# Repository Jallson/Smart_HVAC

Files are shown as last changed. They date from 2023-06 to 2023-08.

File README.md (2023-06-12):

# Smart_HVAC_by_Jallson_Suryo
### Problem:
The problem often found in HVAC systems is that energy got wasted because the system uses more energy than necessary or the system cannot quickly adjust to the changing needs in a dynamic environment. To tackle the problem, we need a system that manages its power intensity based on what is necessary for each zones in real-time for a given environment. The power intensity necessary for each zones can be derived from the following data: number of person, time duration spent inside, and/or the person’s activity.

### Our Solution:
Smart HVAC System that can optimize energy consumption by adjusting the power intensity in different zones inside an office or a residential space (zones with more people, more activity and longer time durations will need more cooling/heating and vice versa). The zone heat mapping will be generated using data obtained from Nicla Vision (with Edge Impulse's FOMO ML model embedded) that’s mounted like a surveillance camera inside the space.

### Description:
The project uses Edge Impulse’s FOMO to detect multiple objects and its coordinates using a compact micro-controller with on-board camera (Nicla Vision). The object detection ML model will use the top view of miniature figures with standing and sitting positions as objects. The data captured will be divided into training and test data. Then the Impulse with Image and Object Detection as learning blocks and grayscale color blocks will be created. The accuracy result for this training and test model is above 90% so there is confidence when counting the number of objects (person) and tracking its centroid coordinates. The ML model is then deployed to the Nicla Vision. The number of objects in each zone is displayed into the OLED display. The Nicla Vision also communicates to an Arduino Nano via I2C which we are using for the fan speed controller. This system will increase fan intensity on areas/zone that need more cooling/heating, which means more activity/people on a certain zone will increase fan intensity on that zone. The total HVAC power output can also be adjusted based on the total number of people in the space. The project is a proof of concept (PoC) using a 1:50 scale model with an office interior with several partitions and furniture and miniature figures. The space is divided into 4 zones, each zone has a small fan installed. The OLED display is used in this PoC to show the output of this simulation.

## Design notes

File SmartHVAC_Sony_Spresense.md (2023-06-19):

## Smart HVAC System with Sony Spresense by Jallson Suryo

This is an alternative version of the Smart HVAC project using the Sony Spresense development board. The Nicla Vision version of this project can be found here: (https://github.com/Jallson/Smart_HVAC/blob/main/HVAC_Smart_System.md)

Demo Video link: https://youtu.be/LLYOtY7svDQ
Edge Impulse project link: https://studio.edgeimpulse.com/public/215243/latest


Smart HVAC with Sony Spresense camera - PoC Demo setup




Diagram Smart HVAC with Sony Spresense expansion board with Camera

All the steps from 1 to 5 (skipping part 4) is the same with the previous project; Sony Spresense does not use the Open MV IDE hence part 4 can be skipped. In part 5, Deploying the program via the Arduino IDE, we have modified the code, which can be downloaded here (https://github.com/Jallson/Smart_HVAC/blob/main/spresense_camera_smartHVAC_oled.ino) and the code for the Arduino Nano peripheral *Nano_SmartHVAC_I2C_Peripheral.ino* can be downloaded here (https://github.com/Jallson/Smart_HVAC/blob/main/Nano_SmartHVAC_I2C_Peripheral.ino).


### Conclusion
By using Sony Spresense, this Smart HVAC project successfully demonstrates that the flexibility of the ML model using Edge Impulse can be directly applied to different types of Micro-controllers with only minimal modification needed. This Sony Spresense development board has the potential with more RAM and a larger Sony camera sensor than the Nicla Vision.

Additional case design for Sony Spresense for this project:



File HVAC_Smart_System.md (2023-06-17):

## Smart HVAC System with Nicla Vision by Jallson Suryo



Edge Impulse project link: https://studio.edgeimpulse.com/public/215243/latest
Demo Video link (unlisted): https://youtu.be/QgQMWRZAlcY

### Problem:
The problem often found in HVAC systems is that energy got wasted because the system uses more energy than necessary or the system cannot quickly adjust to the changing needs in a dynamic environment. To tackle the problem, we need a system that manages its power intensity based on what is necessary for each zones in real-time for a given environment. The power intensity necessary for each zones can be derived from the following data: number of person, time duration spent inside, and/or the person’s activity.

### Our Solution:
Smart HVAC System that can optimize energy consumption by adjusting the power intensity in different zones inside an office or a residential space (zones with more people, more activity and longer time durations will need more cooling/heating and vice versa). The zone heat mapping will be generated using data obtained from Nicla Vision (with Edge Impulse's FOMO ML model embedded) that’s mounted like a surveillance camera inside the space.

### Description:
The project uses Edge Impulse’s FOMO to detect multiple objects and its coordinates using a compact micro-controller with on-board camera (Nicla Vision). The object detection ML model will use the top view of miniature figures with standing and sitting positions as objects. The data captured will be divided into training and test data. Then the Impulse with Image and Object Detection as learning blocks and grayscale color blocks will be created.
The accuracy result for this training and test model is above 90% so there is confidence when counting the number of objects (person) and tracking its centroid coordinates.

The ML model is then deployed to the Nicla Vision. The number of objects in each zone is displayed into the OLED display. The Nicla Vision also communicates to an Arduino Nano via I2C which we are using for the fan speed controller.
This system will increase fan intensity on areas/zone that need more cooling/heating, which means more activity/people on a certain zone will increase fan intensity on that zone. The total HVAC power output can also be adjusted based on the total number of people in the space. 
The project is a proof of concept (PoC) using a 1:50 scale model with an office interior with several partitions and furniture and miniature figures. The space is divided into 4 zones, each zone has a small fan installed. The OLED display is used in this PoC to show the output of this simulation.





Arduino Nicla Vision, aluminium extrusion frame, and 3D printed miniature model (1:50)
System Diagram , prototyping in breadboard, and Smart HVAC System with custom design PCB

#### Hardware Component:

- Arduino Nicla Vision
- Arduino Nano
- 2x TB6612 Motor drivers
- 4x DC 5V mini fan 3cm
- 0.96inch OLED display
- Aluminium extrusion as a standee
- 3D printed (case, office interior 1:50 miniature)
- Powerbank & battery for Nicla Vision

#### Software & Online Services:

- Edge Impulse Studio
- Arduino IDE
- OpenMV IDE

### Steps:

#### 1. Prepare Data / Photos

In this project we will use a smartphone camera to capture the images for data collection for ease of use. Take picture from above in different positions with backgrounds of varying angles lighting condition to ensure that the model can work under slightly different conditions (to prevent overfitting). FYI, lighting and object size are crucial aspect to ensure the performance of this model.
Note: Keep the size of the objects similar in size in the pictures. Significant difference in object size will confuse the FOMO algorithm.

#### 2. Data acquisition, and labelling

Open studio.edgeimpulse.com , login (or create an account first) then create a new project.
Choose Images project option, then Classify Multiple Objects. In Dashboard > Project Info, choose Bounding Boxes for labelling method and Nicla Vision for target device. Then in Data acquisition, click on Upload Data tab, choose your photo files, auto split, then click Begin upload.
Click on Labelling queue tab then start drag a box around an object and label it (person) and Save. Repeat.. until all images labelled. 



Make sure that the ratio between Training and Test data is ideal, around 80/20.

#### 3. Training and building model using FOMO Object Detection
Once you have the dataset ready, go to Create Impulse and set 96 x 96 as image width - height (this help in keeping the ML model small in memory size). Then choose Fit shortest axis, and choose Image and Object Detection as learning blocks.
Go to Image parameter section, select color depth as Grayscale then press Save parameters. Then click on Generate and navigate to Object Detection section, and leave training setting for Neural Network as it is — in our case is quite balanced pre-trained model, then we choose FOMO (MobileNet V2 0.35). Train the model by press the Start training.. and you can see the progress.
If everything is OK, then we can test the model, go to Model Testing section and click Classify all. Our result is above 90%, then we can move on to the next step — deployment.






#### 4. Deploy to OpenMV firmware and test it.



To use the OpenMV firmware, you will need the OpenMV IDE installed in your computer. Once you have the IDE ready, if you check the downloaded zip folder you will find a number of files. We will need the following files:
*edge_impulse_firmware_arduino_nicla_vision.bin* and *ei_object_detection.py*. The next step is loading the downloaded firmware containing the ML model to the Nicla Vision board. So go back to OpenMV and go to Tools -> Run Bootloader (Load Firmware), select the *.bin* file in the unzipped folder, and click Run.

Next, we will run the python code. Go to File -> Open File and select the .py python file from the unzipped folder. Once the file is opened, connect the Nicla Vision board, select the serial/com port and click the green “play” button. The program should be running now and you can see the FOMO object detection will run live on a small window.


#### 5. Deploy and Build an Arduino program



You should have the Arduino IDE installed on your computer for the following step. Once the Edge Impulse Arduino Firmware is built, downloaded and unzipped, you should download the *nicla_vision_camera_smartHVAC_oled.ino* code which can be downloaded here (https://github.com/Jallson/Smart_HVAC/blob/main/nicla_vision_camera_smartHVAC_oled.ino) and place it inside the unzipped folder from Edge Impulse. Once the *.ino* code is inside Edge Impulse unzipped folder, move it to your Arduino folder on your computer. Now you can upload the *.ino* code to your Nicla Vision board via the Arduino IDE.
The *.ino code* is a modified version of the Edge Impulse example code for object detection on Nicla Vision. The modification adds capability to display person count on each room to the OLED screen and act as the controller to the Arduino Nano I2C peripheral. The code distinguishes the four rooms using four quadrants and by knowing the X, Y coordinates of the object’s centroid we can locate the person. The Arduino Nano adjusts the fan motor using PWM based on the number of person present in the room.

The code for the Arduino Nano peripheral *Nano_SmartHVAC_I2C_Peripheral.ino* can be downloaded here (https://github.com/Jallson/Smart_HVAC/blob/main/Nano_SmartHVAC_I2C_Peripheral.ino).

Prototype test video: https://youtube.com/shorts/DnW0lFKFCdk?feature=share

### Conclusion

Finally, we have successfully implemented this object detection model into Arduino Nicla Vision and use the data captured from the camera to automatically control the HVAC system’s fans’ power intensity and then display the occupancy number and power meter for each zones. I believe this Proof of Concept project can be implemented in the real world HVAC system, so that the goal of optimizing room temperature and saving energy can be achieved for a better more sustainable future.

Check again our complete demo video: 
https://youtu.be/QgQMWRZAlcY

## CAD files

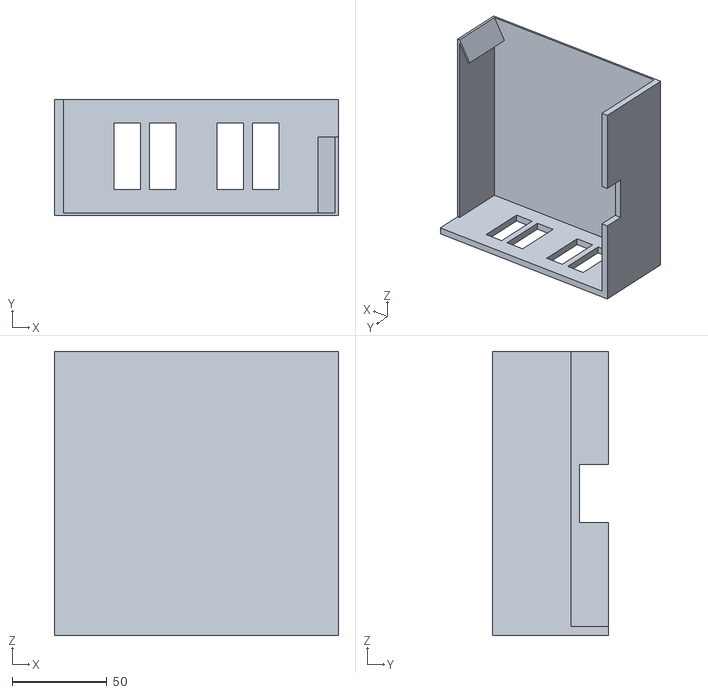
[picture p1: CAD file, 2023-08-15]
3d_files/plan_office 1of4.stl
150.0 x 61.4 x 150.0

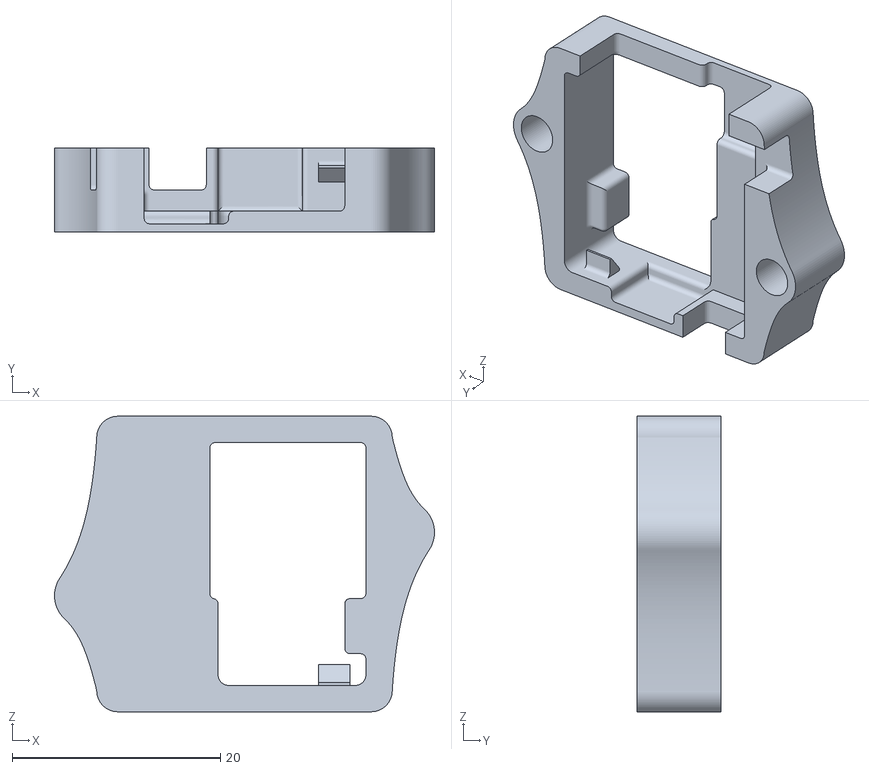
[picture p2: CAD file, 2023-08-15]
3d_files/Nicla_front.stl
36.5 x 8.12 x 28.4

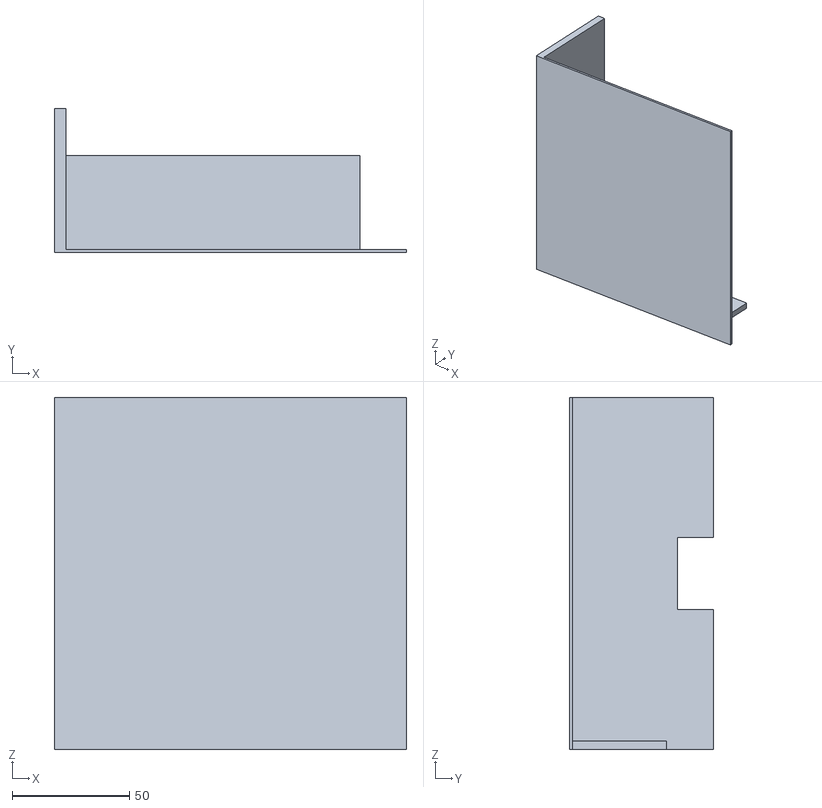
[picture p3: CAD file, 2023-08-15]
3d_files/plan_office 2of4.stl
150.0 x 61.4 x 150.0

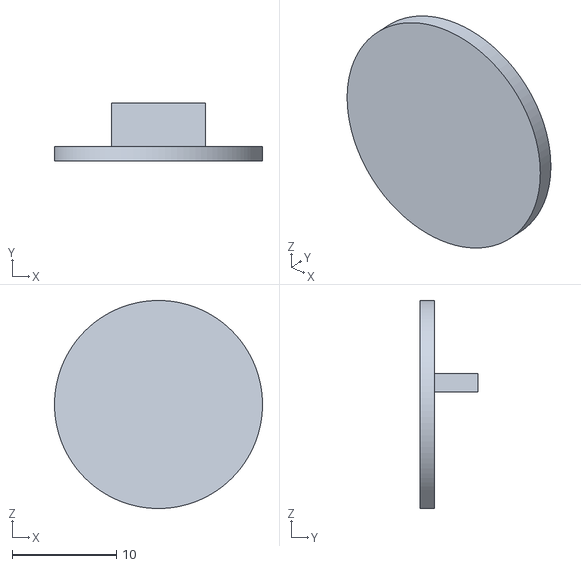
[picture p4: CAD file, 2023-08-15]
3d_files/figure_standing_pad.stl
20.0 x 5.60 x 20.0

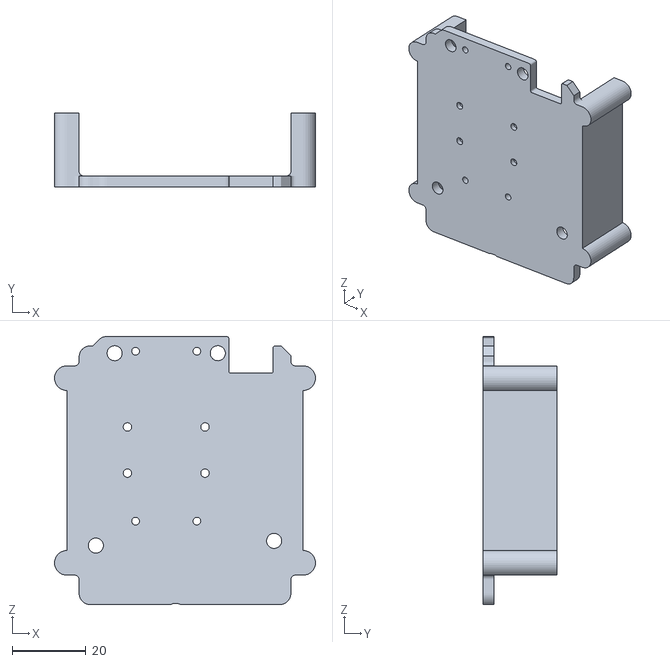
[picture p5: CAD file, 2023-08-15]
3d_files/sony_bottomcase_hvac.stl
70.7 x 20.0 x 72.6

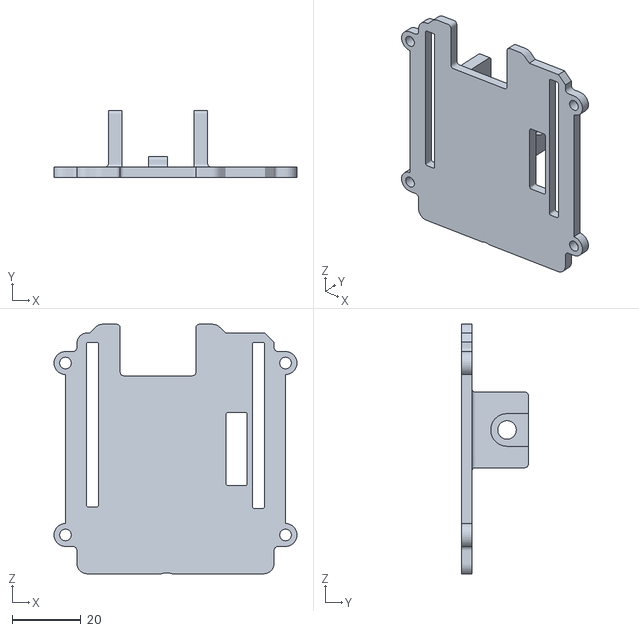
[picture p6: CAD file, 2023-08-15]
3d_files/Sony_topcase_hvac.stl
70.7 x 19.4 x 72.6

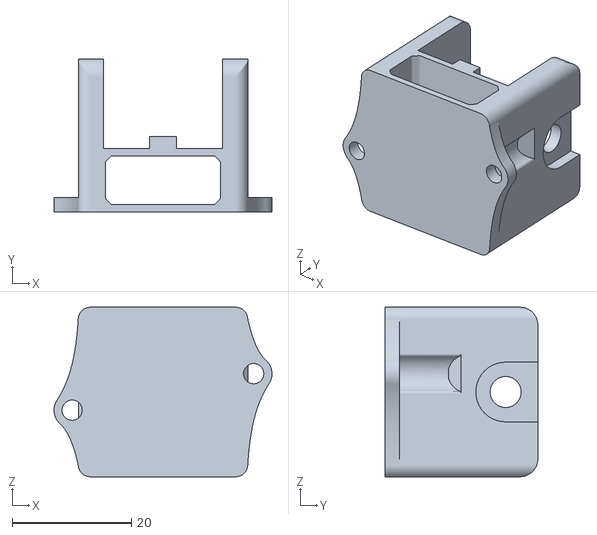
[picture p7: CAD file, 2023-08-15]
3d_files/Nicla_Bottom.stl
36.5 x 25.6 x 28.4

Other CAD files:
3d_files/plan_office 3of4.stl
3d_files/plan_office 4of4.stl

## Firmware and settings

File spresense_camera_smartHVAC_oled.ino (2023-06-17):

 /***
 * Some of this code came from edge impulse's example and                           *
 * modifications to M. Marcial's code.                                              *
 * Hence, the following Edge Impulse and M. Marcial's copyright statement.          *
 *----------------------------------------------------------------------------------*
 * Edge Impulse Arduino examples                                                    *
 * Copyright (c) 2021 EdgeImpulse Inc.                                              *
 * M. Marcial "Spresense-VisionModel.ino"                                           *
 * Copyright (c) 2022 M. Marcial                                                    *
 *                                                                                  *
 * Permission is hereby granted, free of charge, to any person obtaining a copy     *
 * of this software and associated documentation files (the "Software"), to deal    *
 * in the Software without restriction, including without limitation the rights     *
 * to use, copy, modify, merge, publish, distribute, sublicense, and/or sell        *
 * copies of the Software, and to permit persons to whom the Software is            *
 * furnished to do so, subject to the following conditions:                         *
 *                                                                                  *
 * The above copyright notice and this permission notice shall be included in       *
 * all copies or substantial portions of the Software.                              *
 *                                                                                  *
 * THE SOFTWARE IS PROVIDED "AS IS", WITHOUT WARRANTY OF ANY KIND, EXPRESS OR       *
 * IMPLIED, INCLUDING BUT NOT LIMITED TO THE WARRANTIES OF MERCHANTABILITY,         *
 * FITNESS FOR A PARTICULAR PURPOSE AND NONINFRINGEMENT. IN NO EVENT SHALL THE      *
 * AUTHORS OR COPYRIGHT HOLDERS BE LIABLE FOR ANY CLAIM, DAMAGES OR OTHER           *
 * LIABILITY, WHETHER IN AN ACTION OF CONTRACT, TORT OR OTHERWISE, ARISING FROM,    * 
 * OUT OF OR IN CONNECTION WITH THE SOFTWARE OR THE USE OR OTHER DEALINGS IN THE    *
 * SOFTWARE.                                                                        *
 *                                                                                  *
 ************************************************************************************
 ***/

////////////////////////////////////////////////////////////////////////////////////////////////////////////////////
//                      MEMORY INFO                                                                               //
//                      The program requires a minimum MainCore memory of 1024 kB                                 //
////////////////////////////////////////////////////////////////////////////////////////////////////////////////////

/***
//------------------------------------------------------------------------------------------------------------------
  Edge Impulse Studio float32 Library Estimates: RAM 131k, Flash 182
//------------------------------------------------------------------------------------------------------------------

  Target 1152 kB
  *** ---> Works!
  Sketch uses           393,424 bytes (33%) of program storage space.
  Maximum is          1,179,648 bytes.
  Global variables use  393,424 bytes (33%) of dynamic memory,
  leaving               786,224 bytes for local variables.
  Maximum is          1,179,648 bytes.

  Target 1024 kB
  *** ---> Works!
  Sketch uses           393,392 bytes (37%) of program storage space.
  Maximum is          1,048,576 bytes.
  Global variables use  393,392 bytes (37%) of dynamic memory,
  leaving               655,184 bytes for local variables.
  Maximum is          1,048,576 bytes.
  
  Target 896 kB
  *** --->  ERR: failed to allocate tensor arena
                 Failed to allocate TFLite arena (error code 1)
                 ERROR: Failed to run classifier in camera_classify(). Err=-6
  Sketch uses           393,336 bytes (42%) of program storage space.
  Maximum is            917,504 bytes.
  Global variables use  393,336 bytes (42%) of dynamic memory,
  leaving               524,168 bytes for local variables.
  Maximum is            917,504 bytes.                 

  Target 768 kB
  *** ---> Executes CamCB() once then crashes
  Sketch uses           393,336 bytes (50%) of program storage space.
  Maximum is            786,432 bytes.
  Global variables use  393,336 bytes (50%) of dynamic memory,
  leaving               393,096 bytes for local variables.
  Maximum is            786,432 bytes.
  
  Target 640 kB
  *** ---> Executes CamCB() once then crashes
  Sketch uses            393,336 bytes (60%) of program storage space.
  Maximum is             655,360 bytes.
  Global variables use   393,336 bytes (60%) of dynamic memory,
  leaving                262,024 bytes for local variables.
  Maximum is             655,360 bytes.
  
  Target 512 kB
  *** ---> Gets to loop(), then crashes.
  Sketch uses           393,336 bytes (74%) of program storage space.
  Maximum is            524,288 bytes.
  Global variables use  393,336 bytes (74%) of dynamic memory,
  leaving               130,952 bytes for local variables.
  Maximum is            524,288 bytes.

////////////////////////////////////////////////////////////////////////////////////////////////////////////////////
//                      PROGRAMMING INFO                                                                          //
//                      If Arduino fails to program the Spresense, execute the following command line.            //
//                      Change "<your_path>" depending on your system configuration                               //
//                      Change "/dev/ttyUSB0" to serial port the Spresense connected to.                          //
////////////////////////////////////////////////////////////////////////////////////////////////////////////////////
  
  My Ardy Build Folder: C:\Users\mmarc\AppData\Local\Temp\arduino-sketch-FCC2488F5F48E4ED1B9D9484E3902BF5
  
  Flash from Ubuntu:
      "<your_path>/.arduino15/packages/SPRESENSE/tools/spresense-tools/2.6.0/flash_writer/linux/flash_writer"
      -s -c
      "/dev/ttyUSB0"
      -d -n
      "/tmp/arduino-sketch-<a_randon_32-bit_hex_value>>/Spresese-CameraModel.ino.spk"
  
  Flash from Windows:
    "C:\Users\<username>\AppData\Local\Arduino15\packages\SPRESENSE\tools\spresense-tools\2.6.0/flash_writer/windows/flash_writer.exe"
    -s -c
    "COM11"
    -d -n
    "C:\Users\<username>\AppData\Local\Temp\arduino-sketch-<a_randon_32-bit_hex_value>/Spresense-AudioModel.ino.spk"
//------------------------------------------------------------------------------------------------------------------
***/

/* Defines & Includes ------------------------------------------------------------------------------------------- */
// The following are not supported on a SubCore (there may be others):
//                                                                      Audio.h,
//                                                                      Camera.h,
//                                                                      File.h,
//                                                                      MemoryUtil.h
#ifdef SUBCORE
#error "Core selection is wrong!! Must compile to MainCore!!!"
#endif

///#define EI_CLASSIFIER_HAS_MODEL_VARIABLES       1
///#define EI_CLASSIFIER_INPUT_FRAMES              1
///#define EI_CLASSIFIER_INTERVAL_MS               1
///#define EI_CLASSIFIER_TFLITE_OUTPUT_DATA_TENSOR 1 //0
///#define EI_CLASSIFIER_FULL_TFLITE               1 //NA
///#define EI_CLASSIFIER_OBJECT_DETECTION          0 //1
//#include <Cup_inferencing.h>                // Either int8 or float model exported from the Edge Impulse Studio as an Arduino library works.
#include <Smart_HVAC_inferencing.h>

#include <Wire.h>
#include <Adafruit_GFX.h>
#include <Adafruit_SSD1306.h>

#include <Camera.h>                         // Sony's camera library.

/* The following #defines define the center, crop, and resize of the image to the Impulse image size.
   We will use the Spresense hardware accelerator inside the CPU CXD5602.
   NOTE: EI_CLASSIFIER_INPUT width and height must be less than RAW_HEIGHT * SCALE_FACTOR, and must
   simultaneously meet the requirements of the Spresense api:
   https://developer.sony.com/develop/spresense/developer-tools/api-reference/api-references-arduino/group__camera.html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
*/
#define SCALE_FACTOR 1
// Camera Specs:
//              2608 (H) x 1960 (V) = approx. 5.11 M pixels
//              Y/C, RGB and JPEG

//The Spresense HW accelerator can only handle:
//  Maximum width  is  768 pixels.
//  Maximum height is 1024 pixels.

//#define RAW_WIDTH  CAM_IMGSIZE_QQVGA_H   // 160 <-- Classifies ok.
//#define RAW_HEIGHT CAM_IMGSIZE_QQVGA_V   // 120

#define RAW_WIDTH    CAM_IMGSIZE_QVGA_H    // 320 <-- Classifies ok.
#define RAW_HEIGHT   CAM_IMGSIZE_QVGA_V    // 240

//#define RAW_WIDTH  CAM_IMGSIZE_VGA_H     // 640 <--!!!Although the HW can handle this the app crashes!!!
//#define RAW_HEIGHT CAM_IMGSIZE_VGA_V     // 480

//#define RAW_WIDTH  CAM_IMGSIZE_HD_H      //1280 <-- Exceeds HW accellerator maximum width of 768 pixels. 
//#define RAW_HEIGHT CAM_IMGSIZE_HD_V      // 720   

//#define RAW_WIDTH  CAM_IMGSIZE_QUADVGA_H //1280 <-- Exceeds HW accellerator maximum width of 768 pixels. 
//#define RAW_HEIGHT CAM_IMGSIZE_QUADVGA_V // 960

//#define RAW_WIDTH  CAM_IMGSIZE_FULLHD_H  //1920 <-- Exceeds HW accellerator maximum width of  768 pixels. 
//#define RAW_HEIGHT CAM_IMGSIZE_FULLHD_V  //1080 <-- Exceeds HW accellerator maximum height of 1024 pixels. 

//#define RAW_WIDTH  CAM_IMGSIZE_3M_H      //2048 <-- Exceeds HW accellerator maximum width of  768 pixels. 
//#define RAW_HEIGHT CAM_IMGSIZE_3M_V      //1536 <-- Exceeds HW accellerator maximum height of 1024 pixels. 

// Verified program !!!crashes!!! with these settings:
//#define RAW_WIDTH  CAM_IMGSIZE_5M_H      //2560 <-- Exceeds HW accellerator maximum width of  768 pixels. 
//#define RAW_HEIGHT CAM_IMGSIZE_5M_V      //1920 <-- Exceeds HW accellerator maximum height of 1024 pixels. 

// We need to clip (crop) the raw image from the camera to be the same size that the Impulse was configured with.
// The following 4 #defines are used to calculate the image:	lefttop_x, lefttop_y, rightbottom_x, & rightbottom_y.
// What is the difference between clip and crop?
// Clip: To limit or reduce the extent of one dataset by the extents or boundary of another.
// Crop: In this context means to cut or trim an image or raster file.
#define CLIP_WIDTH  (EI_CLASSIFIER_INPUT_WIDTH  * SCALE_FACTOR) // EI_CLASSIFIER_INPUT_WIDTH  is defined by the EI Model in "model_metadata.h"
#define CLIP_HEIGHT (EI_CLASSIFIER_INPUT_HEIGHT * SCALE_FACTOR) // EI_CLASSIFIER_INPUT_HEIGHT is defined by the EI Model in "model_metadata.h"
#define OFFSET_X   ((RAW_WIDTH  - CLIP_WIDTH)  / 2)
#define OFFSET_Y   ((RAW_HEIGHT - CLIP_HEIGHT) / 2)

// Oled screen dimensions
#define SCREEN_WIDTH 128
#define SCREEN_HEIGHT 64

#define BARLENGTH 15
#define BARHEIGHT 6

Adafruit_SSD1306 display(SCREEN_WIDTH, SCREEN_HEIGHT, &Wire, -1);

#if EI_CLASSIFIER_INPUT_WIDTH  > RAW_HEIGHT * SCALE_FACTOR
#error "EI_CLASSIFIER_INPUT_WIDTH not compatiable with Spresense hardware accelerator.
#endif

#if EI_CLASSIFIER_INPUT_HEIGTH > RAW_HEIGHT * SCALE_FACTOR
#error "EI_CLASSIFIER_INPUT_WIDTH not compatiable with Spresense hardware accelerator.
#endif

#define DEBUG_IT  false             // Enable for very verbose logging from Edge Impulse SDK.
                                    // Show features from raw data during the Classify().
#define GRAYSCALE true

#define CLASSIFIER_THRESHOLD  0.7   // We will take an action, like saving a snapshot to a SD card
                                    // if the Prediction is above this value.

////////////////////////////////////////////////////////////////////////////////////////////////////////////////////
//                      START GLOBALS                                                                             //
////////////////////////////////////////////////////////////////////////////////////////////////////////////////////

/* Static Variables --------------------------------------------------------------------------------------------- */
       bool    StateLED0     = false;               //Global: Toggle when entering    CamCB()
       bool    StateLED1     = false;               //Global: Toggle before calling   camera_classify()
       bool    StateLED2     = false;               //Global: Toggles when we classify an image with high confidence.
       bool    StateLED3     = false;               //Global: Toggle when entering    ei_camera_cutout_get_data().
static CamImage            sized_img;               //Global: Instatiate a Sony class to control the image from the camera.
static ei_impulse_result_t ei_result = { 0 };       //Global: "results" of Classifier(). This doesn't need to be global.

/* Prototypes --------------------------------------------------------------------------------------------------- */
              void printCamErr(              enum CamErr);
              void CamCB(                    CamImage);
static inline void mono_to_rgb(              uint8_t, uint8_t *, uint8_t *, uint8_t *);
int                ei_camera_cutout_get_data(size_t, size_t, float *);
static        void camera_classify(          bool);
              void camera_start_continuous(  bool);
              void setup();
              void loop();

////////////////////////////////////////////////////////////////////////////////////////////////////////////////////
//                      END GLOBALS                                                                               //
////////////////////////////////////////////////////////////////////////////////////////////////////////////////////

////////////////////////////////////////////////////////////////////////////////////////////////////////////////////
//                      CAMERA HELPER ROUTINES                                                                    //
////////////////////////////////////////////////////////////////////////////////////////////////////////////////////

/*******************************************************************************************************************
 * @brief      Print Camera Error Message
 * @details    
 * @param[in]  err, error number 
 * @return     void
*******************************************************************************************************************/

// initialize arrays
byte room[4] = {};
int line[4] = {16, 29, 42, 55};
int bar[6] = {18, 37, 56, 75, 94, 113};


void printCamErr(enum CamErr err)
{
  //ei_printf("[FLOW] Entering printCamErr(%d)...\n", err);
  
  ei_printf("Error: ");
  switch (err)
  {
    case CAM_ERR_NO_DEVICE:
      ei_printf("No Device.\n");
      break;
    case CAM_ERR_ILLEGAL_DEVERR:
      ei_printf("Illegal device error.\n");
      break;
    case CAM_ERR_ALREADY_INITIALIZED:
      ei_printf("Already initialized.\n");
      break;
    case CAM_ERR_NOT_INITIALIZED:
      ei_printf("Not initialized.\n");
      break;
    case CAM_ERR_NOT_STILL_INITIALIZED:
      ei_printf("Still picture not initialized.\n");
      break;
    case CAM_ERR_CANT_CREATE_THREAD:
      ei_printf("Failed to create thread.\n");
      break;
    case CAM_ERR_INVALID_PARAM:
      ei_printf("Invalid parameter.\n");
      break;
    case CAM_ERR_NO_MEMORY:
      ei_printf("No memory.\n");
      break;
    case CAM_ERR_USR_INUSED:
      ei_printf("Buffer already in use.\n");
      break;
    case CAM_ERR_NOT_PERMITTED:
      ei_printf("Operation not permitted.\n");
      break;
    default:
      ei_printf("Unknown camera error.\n");
      break;
  }
}

/*******************************************************************************************************************
 * @brief      Convert Monochrome Data to RGB Values
 * @param[in]  mono_data  The mono data
 * @param[out] r          red pixel value
 * @param[out] g          green pixel value
 * @param[out] b          blue pixel value
 *******************************************************************************************************************/
 static inline void mono_to_rgb(uint8_t mono_data, uint8_t *r, uint8_t *g, uint8_t *b)
{
  //ei_printf("[FLOW] Entering mono_to_rgb()...\n");
  uint8_t v = mono_data;
  *r = *g = *b = v;
}

////////////////////////////////////////////////////////////////////////////////////////////////////////////////////
//                      EDGE IMPULSE VISION ROUTINES                                                              //
////////////////////////////////////////////////////////////////////////////////////////////////////////////////////

#if GRAYSCALE == true
 
/*******************************************************************************************************************
 * @brief      Convert Grayscale to RGB
 * @details    This is the routine that gets the data for the Impulse "signal".
 * @param[in]  offset,  pixel offset of raw buffer
 * @param[in]  length,  number of pixels to convert
 * @param[out] out_buf, pointer to store output image
 * @return     0
 *******************************************************************************************************************/
int ei_camera_cutout_get_data(size_t offset, size_t length, float *out_ptr)
{
  //ei_printf("[FLOW] Entering Grayscale, ei_camera_cutout_get_data()...\n");    
  StateLED3 = !StateLED3;
  digitalWrite(LED3, StateLED3);
  
  size_t bytes_left = length;
  size_t out_ptr_ix = 0;

  uint8_t *buffer = sized_img.getImgBuff(); // Get grayscale image.

  // Read byte for byte.
  while (bytes_left != 0)
  {
    // Grab the pixel value.
    uint8_t pixel = buffer[offset];

    // Convert to R/G/B.
    uint8_t r, g, b;
    mono_to_rgb(pixel, &r, &g, &b);

    // Save RGB value as a float.
    float pixel_f = (r << 16) + (g << 8) + b;
    out_ptr[out_ptr_ix] = pixel_f;

    // ...and go to the next pixel.
    out_ptr_ix++;
    offset++;
    bytes_left--;
  }

  // RGB image buffer is now ready.
  return 0;
}

#else

/*******************************************************************************************************************
 * @brief      Convert RGB565 raw camera buffer to RGB888.
 * @details    This is the routine that gets the data for the Impulse "signal".
 *             This is from the "nano_ble33_sense_camera.ino" example.
 * @param[in]  offset,  pixel offset of raw buffer
 * @param[in]  length,  number of pixels to convert
 * @param[out] out_buf, pointer to store output image
*******************************************************************************************************************/
int ei_camera_cutout_get_data(size_t offset, size_t length, float *out_ptr)
{
    //ei_printf("[FLOW] Entering RGB565, ei_camera_cutout_get_data()...\n");    
    StateLED3 = !StateLED3;
    digitalWrite(LED3, StateLED3);

    size_t pixel_ix   = offset * 2; 
    size_t bytes_left = length;
    size_t out_ptr_ix = 0;

    // Grab the value and convert to RGB.
    uint8_t *buffer = sized_img.getImgBuff(); // Get RGB565 image.

    // Read byte for byte.
    while (bytes_left != 0)
    {
      uint16_t pixel = (buffer[pixel_ix]   << 8) | 
                        buffer[pixel_ix+1] <<0;
      uint8_t r, g, b;
      r = ( (pixel >> 11 ) & 0x1f) << 3;
      g = ( (pixel >> 5  ) & 0x3f) << 2;
      b =   (pixel & 0x1f)         << 3;

      // Then convert to "out_ptr" format.
      float pixel_f = (r << 16) + 
                      (g <<  8) + 
                      (b <<  0);
      out_ptr[out_ptr_ix] = pixel_f;

      // ...and go to the next pixel.
      out_ptr_ix++;
      pixel_ix+=2;
      bytes_left--;
    }

    // ...and done converting RGB565 raw camera buffer to RGB888.
    return 0;
}
#endif
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
void loop()
{
  //ei_printf("In loop()...\n");
  
  //sleep(100);
}
/* Flowchart ---------------------------------------------------------------------------------------------------- */
/*
            setup()
              camera_start_continuous()                          

            loop()
              Entering CamCB()
                
              Entering camera_classify()
              Entering RGB565, ei_camera_cutout_get_data()
                . . .                
              Entering RGB565, ei_camera_cutout_get_data()

                . . .

              Entering camera_classify()
              Entering RGB565, ei_camera_cutout_get_data()
                . . .                
              Entering RGB565, ei_camera_cutout_get_data()
*/  

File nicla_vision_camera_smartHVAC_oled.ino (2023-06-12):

/* The following code is a modified version of the Edge Impulse example
 * to work for the Smart HVAC project.
 *
 * The original code is copyrighted and licensed as follows:
 * Edge Impulse ingestion SDK
 * Copyright (c) 2022 EdgeImpulse Inc.
 *
 * Licensed under the Apache License, Version 2.0 (the "License");
 * you may not use this file except in compliance with the License.
 * You may obtain a copy of the License at
 * http://www.apache.org/licenses/LICENSE-2.0
 *
 * Unless required by applicable law or agreed to in writing, software
 * distributed under the License is distributed on an "AS IS" BASIS,
 * WITHOUT WARRANTIES OR CONDITIONS OF ANY KIND, either express or implied.
 * See the License for the specific language governing permissions and
 * limitations under the License.
 *
 */

/* Includes ---------------------------------------------------------------- */
#include <Smart_HVAC_inferencing.h>

#include "edge-impulse-sdk/dsp/image/image.hpp"

#include "camera.h"
#include "gc2145.h"
#include <ea_malloc.h>

#include <Wire.h>
#include <Adafruit_GFX.h>
#include <Adafruit_SSD1306.h>

/* Constant defines -------------------------------------------------------- */
#define EI_CAMERA_RAW_FRAME_BUFFER_COLS           320
#define EI_CAMERA_RAW_FRAME_BUFFER_ROWS           240
#define EI_CAMERA_RAW_FRAME_BYTE_SIZE             2

// Oled screen dimensions
#define SCREEN_WIDTH 128
#define SCREEN_HEIGHT 64

#define BARLENGTH 15
#define BARHEIGHT 6

Adafruit_SSD1306 display(SCREEN_WIDTH, SCREEN_HEIGHT, &Wire, -1);

/*
 ** NOTE: If you run into TFLite arena allocation issue.
 **
 ** This may be due to may dynamic memory fragmentation.
 ** Try defining "-DEI_CLASSIFIER_ALLOCATION_STATIC" in boards.local.txt (create
 ** if it doesn't exist) and copy this file to
 ** `<ARDUINO_CORE_INSTALL_PATH>/arduino/hardware/<mbed_core>/<core_version>/`.
 **
 ** See
 ** (https://support.arduino.cc/hc/en-us/articles/360012076960-Where-are-the-installed-cores-located-)
 ** to find where Arduino installs cores on your machine.
 **
 ** If the problem persists then there's not enough memory for this model and application.
 */

#define ALIGN_PTR(p,a)   ((p & (a-1)) ?(((uintptr_t)p + a) & ~(uintptr_t)(a-1)) : p)

/* Edge Impulse ------------------------------------------------------------- */

typedef struct {
    size_t width;
    size_t height;
} ei_device_resize_resolutions_t;

/**
 * @brief      Check if new serial data is available
 *
 * @return     Returns number of available bytes
 */
int ei_get_serial_available(void) {
    return Serial.available();
}

/**
 * @brief      Get next available byte
 *
 * @return     byte
 */
char ei_get_serial_byte(void) {
    return Serial.read();
}

/* Private variables ------------------------------------------------------- */
static bool debug_nn = false; // Set this to true to see e.g. features generated from the raw signal
static bool is_initialised = false;
static bool is_ll_initialised = false;

GC2145 galaxyCore;
Camera cam(galaxyCore);
FrameBuffer fb;

/*
** @brief points to the output of the capture
*/
static uint8_t *ei_camera_capture_out = NULL;

/*
** @brief used to store the raw frame
*/
static uint8_t *ei_camera_frame_mem;
static uint8_t *ei_camera_frame_buffer; // 32-byte aligned

/* Function definitions ------------------------------------------------------- */
bool ei_camera_init(void);
void ei_camera_deinit(void);
bool ei_camera_capture(uint32_t img_width, uint32_t img_height, uint8_t *out_buf) ;
int calculate_resize_dimensions(uint32_t out_width, uint32_t out_height, uint32_t *resize_col_sz, uint32_t *resize_row_sz, bool *do_resize);

// initialize arrays
byte room[4] = {};
int line[4] = {16, 29, 42, 55};
int bar[6] = {18, 37, 56, 75, 94, 113};

/**
* @brief      Arduino setup function
*/

void setup()
{
    // put your setup code here, to run once:
    Serial.begin(115200);
    // join i2c bus
    Wire.begin();
    // comment out the below line to cancel the wait for USB connection (needed for native USB)
    //while (!Serial);
    // connecting to the SSD1306 oled via i2c
    if(!display.begin(SSD1306_SWITCHCAPVCC, 0x3C)) { // 0x3C is the address for oled
      Serial.println(F("SSD1306 allocation failed"));
      for(;;);
    }
    Serial.println("Edge Impulse Inferencing Demo");

    // initialise M4 RAM
    // Arduino Nicla Vision has 512KB of RAM allocated for M7 core
    // and additional 244k (sic!) on the M4 address space
    // allocating 288 kB as in the line below was
    // advised by a member of Arduino team
    malloc_addblock((void*)0x30000000, 288 * 1024);

    if (ei_camera_init() == false) {
        ei_printf("Failed to initialize Camera!\r\n");
    }
    else {
        ei_printf("Camera initialized\r\n");
    }
}
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

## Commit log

2023-06-17 Add files via upload
    Smart HVAC version of Sony Spresense with camera
2023-08-15 Add 3d .stl files
    [Nicla_Bottom.stl, Nicla_front.stl, Sony_topcase_hvac.stl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]
2023-08-15 Add pcb design files
    [Office HVAC-B_Cu.gbr, Office HVAC-B_Mask.gbr, Office HVAC-B_Silkscreen.gbr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]
